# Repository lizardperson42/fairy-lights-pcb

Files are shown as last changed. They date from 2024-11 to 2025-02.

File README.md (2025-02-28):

# fairy-lights-pcb

This repository contains the PCB design files for the fairy lights project.
The project is a set of fairy lights that is attached to a custom PCB and controlled by an ESP8266 microcontroller.
The PCB design files are created using KiCad.

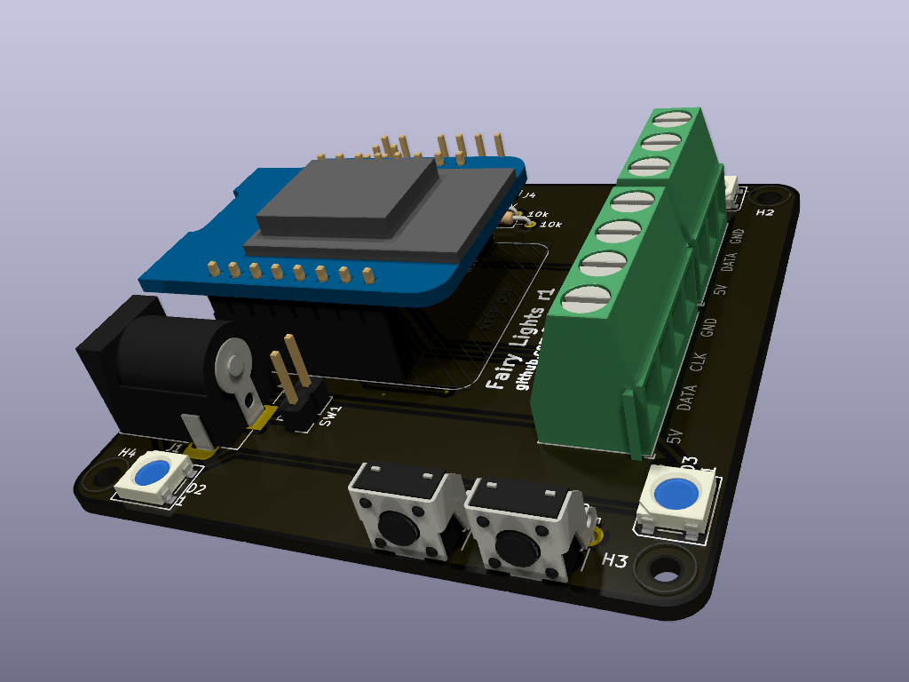
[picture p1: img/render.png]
3D render of the PCB, fully populated


## Parts

- This PCB (1 unit)
- [WeMos D1 Mini ESP8266](https://www.wemos.cc/en/latest/d1/d1_mini.html) (1 unit)
- DC barrel jack, 5.5mm OD, 2.1mm ID (1 unit)
- Screw terminals, 5mm pitch, 4-pin and/or 3-pin (up to 1 unit of each size)
- Pin header, 2.54mm pitch, 1x2 pins (1 unit)
- Pin headers, 2.54mm pitch, 1x4 pins and 2x4 pins (up to 1 unit each)
- WS2812B SMD LEDs (0 or 4 units)
- Vertical tactile push buttons (up to 2 units)
- THT resistors (10kΩ, 0 or 2 units)
- Power switch or jumper for the 2-pin header (1 unit)

### Notes

- The WeMos D1 Mini module can be mounted in various ways.
  The CAD model used here connects it via pin sockets and headers, permitting easy removal and reattachment.
- Any footprint-compatible barrel jack can be used.
- The screw terminals are used to attach connectors for the LED strands, which use wire-to-wire connectors.
- The 2-pin header is interposed between the power jack and the board's 5V rail.
  One can wire up a power switch to it or short it with a jumper.
  Without external power, the board is mostly useless.
  The PCB includes a free area for installing a power switch close to the front-panel buttons.
- The optional pin headers expose the pins of the WeMos D1 Mini module which are not used otherwise.
- The SMD LEDs are connected in a chain around the board; it is not useful to populate only some of them.
- The buttons are directly connected to the microcontroller's GPIO pins.
  - Button USER_A places the microcontroller into flashing mode when pressed during boot-up.
    After boot-up, it can be used to wake the microcontroller from standby mode.
  - Button USER_B cannot trigger standby wake-ups (its state can only be read by polling in software).
- The 4-pin header is connected to the microcontroller's conventional I²C bus pins and the 3.3V rail.
  The THT resistors, if populated, pull its clock and data lines up.
  Without the resistors, the 4-pin header simply exposes the two GPIO pins.
  Together with the 8-pin header's 5V pin, the 4-pin header can be used to drive another LED strand instead.

## Accessories

- 5V DC power supply, suitable current rating, pin positive, sleeve negative, matching the barrel jack
- WS2801 LED strand, JST SM 4-pin connector, particularly [this one](https://www.adafruit.com/product/322) (optional)
- WS2812B LED strand, JST SM 3-pin connector (optional)

The power supply needs to be rated to supply enough current to power the microcontroller and the LED strand(s).
The microcontroller can draw currents of up to 500mA, with typical consumption lower.
Consult your LED strands' user manuals for information about their current requirements.

> [!CAUTION]
> Do not attach the barrel jack and the microcontroller's USB connector simultaneously!

> [!IMPORTANT]
> This board powers the LED strands and on-board LEDs from the 5V rail but controls them using 3.3V signals straight from the ESP8266.
> This pushes the envelope of what their WS28xx driver chips are documented to support.
> This arrangement might work unreliably or not all.

## Connector and microcontroller pin overview

The PCB has the following connectors:

- J1: 5V DC power input, pin positive, sleeve negative
- J2: SPI LED strand connector, 5V power, 3.3V signals
  - Data line is tied to MCU pin D7 (GPIO13)
  - Clock line is tied to MCU pin D5 (GPIO14)
- J3: WS2812 LED strand connector, 5V power, 3.3V signals
  - Data line is tied to MCU pin D6 (GPIO12)
- J4: I²C connector, 3.3V power and signals
  - Data line is tied to MCU pin D2 (GPIO4)
  - Clock line is tied to MCU pin D1 (GPIO5)
- J5: Miscellaneous connector. Layout and MCU pin mapping:
  ```
   GND |1 2| RST
    5V |3 4| A0
  3.3V |5 6| D0
    RX |7 8| TX
  ```
  (pin D0 is also tied to button USER_B)
- SW1: Power switch, separates barrel jack from 5V rail when open.

The microcontroller's pins are used as follows:

| Name | Function | Connector |
| --- | --- | --- |
| GND | Common ground | J1; J2; J3; J4; J5; USB |
| 5V | 5V rail | J1; J2; J3; J5; USB |
| 3.3V | 3.3V rail | J4; J5 |
| RST | Reset | J5 |
| RX (GPIO3)  | UART receive | J5; via USB |
| TX (GPIO1)  | UART transmit | J5; via USB |
| A0 (ADC0) | Analog input | J5 |
| D0 (GPIO16) | Button | SW3 (USER_B) |
| D1 (GPIO5)  | I²C clock | J4 |
| D2 (GPIO4)  | I²C data | J4 |
| D3 (GPIO0)  | Button; MCU flashing  | SW2 (USER_A) |
| D4 (GPIO2)  | MCU module LED | none |
| D5 (GPIO14) | SPI clock | J2 |
| D6 (GPIO12) | WS2812 data | J3 |
| D7 (GPIO13) | SPI data | J2 |
| D8 (GPIO15) | On-board WS2812B LEDs | none |

“USB” refers to the microcontroller module's USB port (5V, GND) or to its USB-to-serial converter chip (RX, TX).

## Case

A case design for this project is given as an OpenSCAD file in `fairy-lights-case/`.
It has been generated from the KiCad design files using [TurboCase](https://turbocase.org) and **manually edited**.
If some parts of the board are not to be populated, the corresponding case cutouts can be removed from the case source file.

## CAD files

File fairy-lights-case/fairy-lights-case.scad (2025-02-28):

/* [Rendering options] */
// Show placeholder PCB in OpenSCAD preview
show_pcb = true;
// Lid mounting method
lid_model = "cap"; // [cap, inner-fit]
// Conditional rendering
render = "case"; // [all, case, lid]


/* [Dimensions] */
// Height of the PCB mounting stand-offs between the bottom of the case and the PCB
standoff_height = 5;
// PCB thickness
pcb_thickness = 1.6;
// Bottom layer thickness
floor_height = 1.2;
// Case wall thickness
wall_thickness = 1.2;
// Space between the top of the PCB and the top of the case
headroom = 16.0;
// Lid edge thickness
lid_edge = 6.5;

/* [M2.5 screws] */
// Outer diameter for the insert
insert_M2_5_diameter = 3.27;
// Depth of the insert
insert_M2_5_depth = 3.75;

/* [Hidden] */
$fa=$preview ? 10 : 4;
$fs=0.2;
inner_height = floor_height + standoff_height + pcb_thickness + headroom;

module wall (thickness, height) {
    linear_extrude(height, convexity=10) {
        difference() {
            offset(r=thickness)
                children();
            children();
        }
    }
}

module bottom(thickness, height) {
    linear_extrude(height, convexity=3) {
        offset(r=thickness)
            children();
    }
}

module lid(thickness, height, edge) {
    linear_extrude(height, convexity=10) {
        offset(r=thickness)
            children();
    }
    translate([0,0,-edge])
    difference() {
        linear_extrude(edge, convexity=10) {
                offset(r=-0.2)
                children();
        }
        translate([0,0, -0.5])
         linear_extrude(edge+1, convexity=10) {
                offset(r=-1.2)
                children();
        }
    }
}


module box(wall_thick, bottom_layers, height) {
    if (render == "all" || render == "case") {
        translate([0,0, bottom_layers])
            wall(wall_thick, height) children();
        bottom(wall_thick, bottom_layers) children();
    }
    
    if (render == "all" || render == "lid") {
        translate([0, 0, height+bottom_layers+0.1])
        lid(wall_thick, bottom_layers, lid_model == "inner-fit" ? headroom-2.5: lid_edge)
            children();
    }
}

module mount(drill, space, height) {
    translate([0,0,height/2])
        difference() {
            cylinder(h=height, r=(space/2), center=true);
            cylinder(h=(height*2), r=(drill/2), center=true);
            
            translate([0, 0, height/2+0.01])
                children();
        }
        
}

module connector(min_x, min_y, max_x, max_y, height) {
    size_x = max_x - min_x;
    size_y = max_y - min_y;
    translate([(min_x + max_x)/2, (min_y + max_y)/2, height/2])
        cube([size_x, size_y, height], center=true);
}

module Cutout_Power_Jack_substract() {
    offset_out = 15;
    above_pcb = 6.5;
    // 9mm housing on the plug I measured + 0.5mm padding
    diameter = 9 + 1;
    length = 10;

    rotate([0, -90, 0])
    translate([above_pcb, 0, offset_out])
    cylinder(length, diameter/2, diameter/2, center = true);
}

module Cutout_SW_Tactile_SPST_substract() {
    above_pcb = 4;
    offset_out = 4;
    thickness = 3;
    offset_x = 4.5 / 2;
    width = 7.5;
    radius = 1;
    gap = 0.5;

    translate([offset_x, -offset_out, above_pcb])
    rotate([0, 90, -90])
    linear_extrude(height = thickness)
    difference() {
        offset(r = radius)
            square(width - 2 * radius, center = true);
        offset(r = radius - gap)
            square(width - 2 * radius, center = true);
    }
}
module Cutout_SW_Tactile_SPST_add() {
    above_pcb = 4;
    offset_out = 4.8;
    offset_x = 4.5 / 2;
    width = 9;

    thickness = 1;
    height = 1;
    length = width / sqrt(2);

    translate([offset_x, -offset_out, above_pcb])
    rotate([0, 90, 90]) 
    rotate([0, 0, 135]) {
        translate([-thickness/2, -thickness/2, 0])
            cube([thickness, thickness, height]);
        for (angle = [0 : 90 : 90]) {
            rotate([0, 0, angle])
            translate([0, -thickness/2, height]) {
                translate([-thickness/2, 0, 0])
                    cube([length - height, thickness, thickness]);
                multmatrix([[1, 0, 1, -thickness * sqrt(2) / 2],
                            [0, 1, 0, 0],
                            [0, 0, 1, -height],
                            [0, 0, 0, 1]])
                    cube([thickness * sqrt(2), thickness, height + thickness]);
                multmatrix([[1, 0, -1, length - thickness * sqrt(2) / 2],
                            [0, 1, 0, 0],
                            [0, 0, 1, -height],
                            [0, 0, 0, 1]])
                    cube([thickness * sqrt(2), thickness, height + thickness]);
            }
        }
    }
}

module Cutout_Screw_Terminal_1x03_substract() {
    offset_out = 10;
    depth = 5;

    width = 12;
    shift = -1;
    height = 3;

    rotate([0, 0, 0])
    translate([shift, offset_out, 0])
    cube([width, depth, height]);
}

module Cutout_TypeC_substract_D1() {
    // the measured values are a little too small, so 1mm padding
    width = 14.5 + 2;
    height = 7 + 2;

    // distance from motherboard to D1 board - half height of connector
    // (the D1's USB port is on the bottom side and the cutout is centered)
    connector_height = 3.2;
    above_pcb = 10.84 - connector_height / 2;

    // the pins are 25.4mm apart, and the USB port is centered
    offset_x = 12.7;

    offset_out = 27.5;
    depth = 10;

    translate([offset_x, offset_out + 1, above_pcb])
    rotate([0, 90, 90])
    union() {
        cube([height, width - height, depth], center = true);
        translate([0, (width - height) / 2, 0])
            cylinder(depth, height / 2, height / 2, center = true);
        translate([0, -(width - height) / 2, 0])
            cylinder(depth, height / 2, height / 2, center = true);
    }
}

module Cutout_Screw_Terminal_1x04_substract() {
    offset_out = 10;
    depth = 5;

    width = 17;
    shift = -1;
    height = 3;

    translate([shift, offset_out, 0])
    cube([width, depth, height]);
}

module Cutout_PinHeader_Power_substract() {
    // This is very bespoke.
    offset_out = 16.5;
    above_pcb = 2.5;
    offset_x = -2.5;

    width = 14.5;
    height = 8.5;
    length = 5;

    rotate([90, -90, 0])
    translate([above_pcb + height / 2, width / 2 + offset_x, offset_out])
    cube([height, width, length], center = true);
}

module pcb() {
    thickness = 1.6;

    color("#009900")
    difference() {
        linear_extrude(thickness) {
            polygon(points = [[60,63.25], [60.0400075,62.7416025], [60.159055,62.245685], [60.3542175,61.7745325], [60.620685,61.3396825], [60.9518925,60.9518925], [61.3396825,60.620685], [61.7745325,60.3542175], [62.245685,60.159055], [62.7416025,60.0400075], [63.25,60], [116.75,60], [117.2583975,60.0400075], [117.754315,60.159055], [118.2254675,60.3542175], [118.6603175,60.620685], [119.0481075,60.9518925], [119.379315,61.3396825], [119.6457825,61.7745325], [119.840945,62.245685], [119.9599925,62.7416025], [120,63.25], [120,116.75], [119.9599925,117.2583975], [119.840945,117.754315], [119.6457825,118.2254675], [119.379315,118.6603175], [119.0481075,119.0481075], [118.6603175,119.379315], [118.2254675,119.6457825], [117.754315,119.840945], [117.2583975,119.9599925], [116.75,120], [63.25,120], [62.7416025,119.9599925], [62.245685,119.840945], [61.7745325,119.6457825], [61.3396825,119.379315], [60.9518925,119.0481075], [60.620685,118.6603175], [60.3542175,118.2254675], [60.159055,117.754315], [60.0400075,117.2583975], [60,116.75], [60,63.25]]);
        }
    translate([116.75, 116.75, -1])
        cylinder(thickness+2, 1.0999999999999943, 1.0999999999999943);
    translate([116.75, 63.25, -1])
        cylinder(thickness+2, 1.0999999999999943, 1.0999999999999943);
    translate([63.25, 63.25, -1])
        cylinder(thickness+2, 1.0999999999999943, 1.0999999999999943);
    translate([63.25, 116.75, -1])
        cylinder(thickness+2, 1.0999999999999943, 1.0999999999999943);
    }
}
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

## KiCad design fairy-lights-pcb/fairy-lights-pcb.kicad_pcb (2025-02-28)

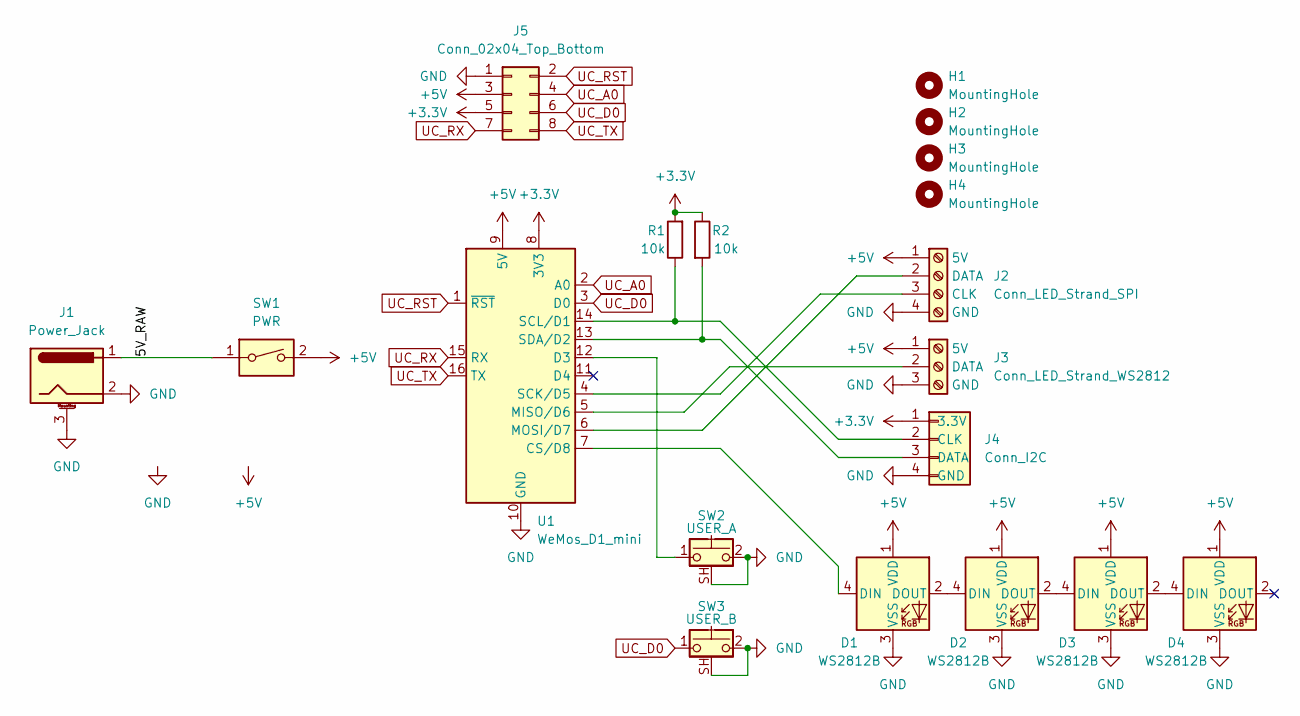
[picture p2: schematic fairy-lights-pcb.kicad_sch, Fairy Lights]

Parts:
D1, D2, D3, D4: WS2812B; LED_WS2812B_PLCC4_5.0x5.0mm_P3.2mm
H1, H2, H3, H4: MountingHole; MountingHole_2.2mm_M2
J1: Power_Jack; BarrelJack_Horizontal
J2: Conn_LED_Strand_SPI; TerminalBlock_LED_Strand_1x04
J3: Conn_LED_Strand_WS2812; TerminalBlock_LED_Strand_1x03
J4: Conn_I2C; PinHeader_1x04_P2.54mm_Vertical
J5: Conn_02x04_Top_Bottom; PinHeader_2x04_P2.54mm_Vertical
R1, R2: 10k; R_Axial_DIN0204_L3.6mm_D1.6mm_P7.62mm_Horizontal
SW1: PWR; PinHeader_Power
SW2: USER_A; SW_Tactile_SPST_Angled_PTS645Vx31-2LFS_SH
SW3: USER_B; SW_Tactile_SPST_Angled_PTS645Vx31-2LFS_SH
U1: WeMos_D1_mini; WEMOS_D1_mini_light

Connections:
+3.3V: J4.1 (3.3V), J5.5, R1.2, R2.1, U1.8 (3V3)
+5V: D1.1 (VDD), D2.1 (VDD), D3.1 (VDD), D4.1 (VDD), J2.1 (5V), J3.1 (5V), J5.3, SW1.2, U1.9 (5V)
/5V_RAW: J1.1, SW1.1
GND: D1.3 (VSS), D2.3 (VSS), D3.3 (VSS), D4.3 (VSS), J1.2, J1.3 (MP), J2.4 (GND), J3.3 (GND), J4.4 (GND), J5.1, SW2.2, SW2.SH (B), SW3.2, SW3.SH (B), U1.10 (GND)
unnamed: D1.4 (DIN), U1.7 (CS/D8)
unnamed: D1.2 (DOUT), D2.4 (DIN)
unnamed: D2.2 (DOUT), D3.4 (DIN)
unnamed: D3.2 (DOUT), D4.4 (DIN)
unnamed: J2.3 (CLK), U1.4 (SCK/D5)
unnamed: J2.2 (DATA), U1.6 (MOSI/D7)
unnamed: J3.2 (DATA), U1.5 (MISO/D6)
unnamed: J4.2 (CLK), R1.1, U1.14 (SCL/D1)
unnamed: J4.3 (DATA), R2.2, U1.13 (SDA/D2)
unnamed: SW2.1, U1.12 (D3)
UC_A0: J5.4, U1.2 (A0)
UC_D0: J5.6, SW3.1, U1.3 (D0)
UC_RST: J5.2, U1.1 (~RST)
UC_RX: J5.7, U1.15 (RX)
UC_TX: J5.8, U1.16 (TX)

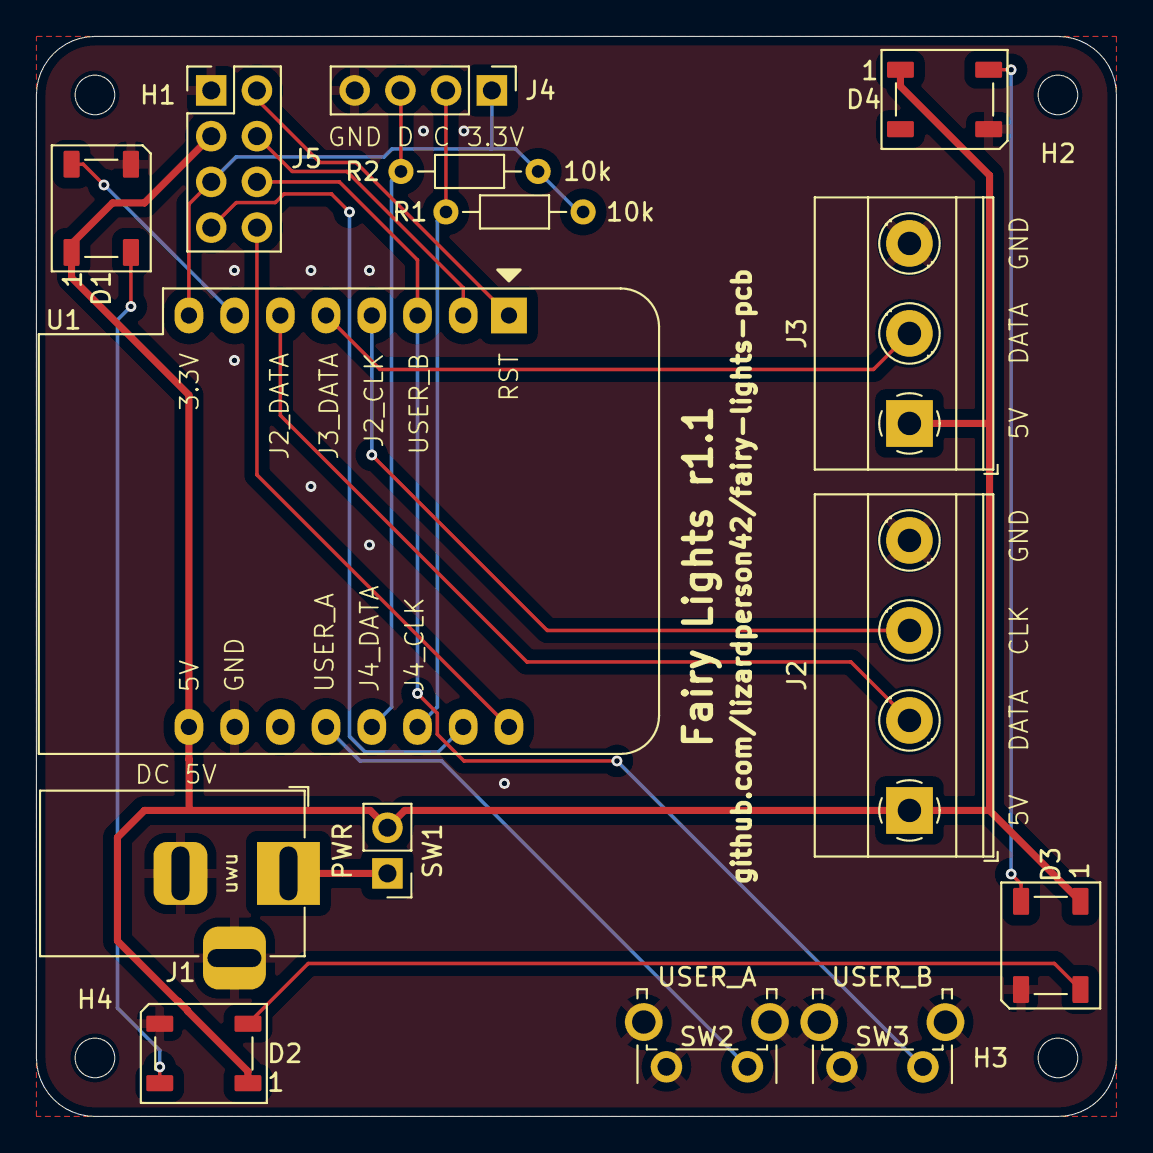
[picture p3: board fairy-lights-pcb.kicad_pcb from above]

Board: 2 copper layers, 60.0 x 60.0 mm, 19 parts (0 on the bottom side), 19 nets.

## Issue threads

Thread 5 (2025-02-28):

Rev. 2 wishlist

lizardperson42, 2025-02-28:
**Major**
- [ ] Moar current
  - [ ] On-board power regulators?
  - [ ] Higher-voltage barrel jack or go all in on USB-PD?
- [ ] Different microcontroller (ESP32)
- [ ] Status display
  - [ ] Cheap or RGB-capable?
  - [ ] Mounted into case edge or case top?
- [ ] Shrink board to 5cm×5cm for panelizability?

**Minor**
- [ ] Swap A0 and D0 pins in J5 to permit a deep-sleep jumper (for whatever that is worth)
- [ ] Increase margin between mounting holes and board edge
- [ ] Change mounting hole diameter
- [ ] Move screw terminals further inside
- [ ] Make power switch header angled?
- [ ] Centered mounting hole for fixating case lids
- [ ] More bypass capacitors (than zero)?

**Jokes**
- [ ] More RGB LEDs

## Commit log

2024-11-08 init project in keycad
    [fairy-lights-pcb.kicad_pcb, fairy-lights-pcb.kicad_sch]
2024-11-08 add custom footprint & symbol libary
2024-11-08 change color of pcb
    [fairy-lights-pcb.kicad_pcb]
2024-11-08 add Custom footprint for TXS0108E
2024-11-08 Add basic schematic
    [fairy-lights-pcb.kicad_sch]
2024-11-08 Add board design and missing component footprints
    [fairy-lights-pcb.kicad_pcb, fairy-lights-pcb.kicad_sch]
2024-11-08 Add resistor value and connector annotations
    [fairy-lights-pcb.kicad_pcb, fairy-lights-pcb.kicad_sch]
2024-11-09 Add more stuff
    - Two more output headers (functionally identical but one labeled like
    the first LED one and the second generically)
    - Header for a power switch (interposed between the power jack and the
    5V rail)
    - Header for a user switch/button (from a GPIO pin to ground)
    - User LED (from a GPIO pin to ground)
    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
    [fairy-lights-pcb.kicad_pcb, fairy-lights-pcb.kicad_sch]
2024-11-09 Add labels; fix DRC complaints
    [fairy-lights-pcb.kicad_pcb]
2024-11-09 Avoid accidentally deleting mounting holes
    [fairy-lights-pcb.kicad_pcb]
2024-11-09 Increase thickness of 5V traces
    Also redoes all routing, because why not.
    [fairy-lights-pcb.kicad_pcb, fairy-lights-pcb.kicad_sch]
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2024-11-10 Add mounting holes to schematic
    This should mollify the design rule checker.
    [fairy-lights-pcb.kicad_pcb, fairy-lights-pcb.kicad_sch]
2024-11-10 Update level shifter in PCB to include 3D model
    [fairy-lights-pcb.kicad_pcb]
2024-11-10 Connect barrel jack mounting pin to ground
    [fairy-lights-pcb.kicad_pcb, fairy-lights-pcb.kicad_sch]
2024-11-10 Update user LED resistor value
    [fairy-lights-pcb.kicad_pcb, fairy-lights-pcb.kicad_sch]
2024-11-10 Tweak board dimensions
    They were *so close* to 6cm x 6cm, I couldn't (haha!) resist.
    [fairy-lights-pcb.kicad_pcb]
2024-11-10 Align PCB edges to centimeter boundaries
    [fairy-lights-pcb.kicad_pcb]
2024-11-10 Tweak level shifter model scale
    It's still not perfectly aligned, but at least the misalignment is less
    obvious.
    [fairy-lights-pcb.kicad_pcb]
2024-11-11 Make room for power switch
    [fairy-lights-pcb.kicad_pcb]
2024-11-11 Move mounting holes closer to rest of schematic
    [fairy-lights-pcb.kicad_sch]
2024-11-11 Update pins and labels
    - All MCU pin silkscreen labels should now be correct.
    - The board title is updated to say "r(evision)" instead of "v(ersion)".
    - The middle pins of J3 and J4 are swapped for totally valid reasons
    (viz. schematic symmetry).
    - J4 is turned into a LED strand connector (such that its pin labels
    match the I2C functions of the corresponding MCU pins).
    - Traces are rerouted to account for the schematic changes and to reduce
    ugly spots.
    [fairy-lights-pcb.kicad_pcb, fairy-lights-pcb.kicad_sch]
2024-11-11 Use different status LED
    [fairy-lights-pcb.kicad_pcb, fairy-lights-pcb.kicad_sch]
2024-11-13 Moar LEDs
    We're also considering yeeting or replacing the level shifter. Until we
    decide on what the replacement will be, I'll leave the current one in,
    with the understanding that one could substitute a pin-compatible and
    working replacement.
    [fairy-lights-pcb.kicad_pcb, fairy-lights-pcb.kicad_sch]
2024-11-17 Make the corners round
    The round parts of the corner edge cuts should be concentric with the
    mounting holes.
    [fairy-lights-pcb.kicad_pcb]
2024-11-23 Yeet level shifter; update interfaces
    - The level shifter we planned to use seems not to work on a breadboard.
    - Driving the LED controllers with 3.3V signals directly instead seems
    to work (although it is out-of-spec or barely at the boundary of what
    is in-spec).
    - LED strands are now attached via screw terminals. (Of course, one can
    choose not to populate them and solder wires directly to the pads
    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
    [fairy-lights-pcb.kicad_pcb, fairy-lights-pcb.kicad_sch]
2024-11-24 Ground the mounting pins of the buttons
    Also tweaks the location of the "5V 2A" label.
    [fairy-lights-pcb.kicad_pcb, fairy-lights-pcb.kicad_sch]
2024-11-24 Tweak push button footprint
    Oh, hey, one can assign multiple footprint pads to the same schematic
    pin!
    [fairy-lights-pcb.kicad_pcb, fairy-lights-pcb.kicad_sch]
2024-11-24 Tweak MCU pin assignment
    - Swaps the J3_DATA and USER_B pins.
    - Now, all LED strand terminals and the I2C header are connected to GPIO
    pins with no strings (or, more accurately, random components on the
    MCU module) attached.
    - Button USER_B puts the MCU flash mode if pressed at boot-up. The same
    can be achieved via USB, but, I guess, it's useful for flashing in the
    field with no USB but a UART?
    - Button USER_A is tied to the same pin that drives the MCU module's
    on-board LED. When USER_A is pressed, the LED lights up. It might be
    worthwhile to re-wire USER_A to MCU pin D0 in order to free the LED
    and allow using USER_A as a soft power button (although that would
    require regul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
    [fairy-lights-pcb.kicad_pcb, fairy-lights-pcb.kicad_sch]
2024-11-27 Fix component labels and positions
    [fairy-lights-pcb.kicad_pcb, fairy-lights-pcb.kicad_sch]
2024-11-27 Move USER_A button to pin D0
    This allows using it to wake out of deep sleep, and avoids interactions
    with the MCU module's built-in LED. The downside is that the pin has to
    be polled in software while the MCU is running.
    [fairy-lights-pcb.kicad_pcb, fairy-lights-pcb.kicad_sch]
2024-11-28 Update pull-up resistor values in README
2024-11-28 Add header for enabling deep sleep self-wakeup
    [fairy-lights-pcb.kicad_pcb, fairy-lights-pcb.kicad_sch]
2024-11-28 Revert "Add header for enabling deep sleep self-wakeup"
    It is not immediately useful if the same pin is also bound to a button,
    as this effectively turns the button into a reset button. I somewhat
    dislike the idea of placing a reset button right besides the "user"
    button.
    This reverts commit fe8c02f848e9494a1d23cb15ce68f1f10867b81e.
    [fairy-lights-pcb.kicad_pcb, fairy-lights-pcb.kicad_sch]
2024-11-28 Tweak button pin assignment
    Button USER_A is now assigned to pin D3, button USER_B to pin D0.
    Since this device is ultimately meant to be mains-powered, deep sleep
    support is not a priority (additionally, while the MCU is sleeping,
    the LED strand cannot quickly react to external requests delivered via
    WiFi). Therefore, now, button USER_A can act as a soft power button (it
    can even raise interrupts to wake from light sleep!) and also as a
    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
    [fairy-lights-pcb.kicad_pcb, fairy-lights-pcb.kicad_sch]
2024-11-29 Fix button pin labels
    [fairy-lights-pcb.kicad_pcb]
2024-11-29 Tweak more PCB labels
    [fairy-lights-pcb.kicad_pcb]
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2024-12-08 add custom footprints including Turbocase footprints
2024-12-08 Update PCB to use Turbocase-enabled footprints
    [fairy-lights-pcb.kicad_pcb, fairy-lights-pcb.kicad_sch]
2024-12-08 update D1 mini footprint (KiCad 8.0.7)
2024-12-08 Update schematic and PCB to use correct D1 Mini
    [fairy-lights-pcb.kicad_pcb, fairy-lights-pcb.kicad_sch]
2024-12-09 Update USB port cutout
    [fairy-lights-pcb.kicad_pcb]
2024-12-09 Update barrel jack case cutout
    [fairy-lights-pcb.kicad_pcb]
2024-12-09 Add case cutouts for screw terminals
    Sheesh, those crimped wire ends are *huge*.
    [fairy-lights-pcb.kicad_pcb, fairy-lights-pcb.kicad_sch]
2024-12-09 Change layers of case properties
    [fairy-lights-pcb.kicad_pcb]
2024-12-10 Add case interior outline
    [fairy-lights-pcb.kicad_pcb]
2024-12-10 Change 360deg to 0deg
    Why didn't KiCad do that immediately but only now?..
    [fairy-lights-pcb.kicad_pcb]
2024-12-11 Update case modules
    [fairy-lights-pcb.kicad_pcb]
2024-12-16 Increase case margin
    [fairy-lights-pcb.kicad_pcb]
2025-01-16 Change power header to custom footprint
    [fairy-lights-pcb.kicad_pcb, fairy-lights-pcb.kicad_sch]
2025-01-17 Add case cutouts (and supports) for front panel
    [fairy-lights-pcb.kicad_pcb]
2025-01-22 Tweak screw terminal wire windows
    [fairy-lights-pcb.kicad_pcb]
2025-02-24 Add case
    [fairy-lights-case.scad]
2025-02-24 Update revision number and GitHub URL
    [fairy-lights-pcb.kicad_pcb, fairy-lights-pcb.kicad_sch]
